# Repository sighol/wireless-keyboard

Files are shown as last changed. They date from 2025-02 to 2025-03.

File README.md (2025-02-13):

# Sighol-44

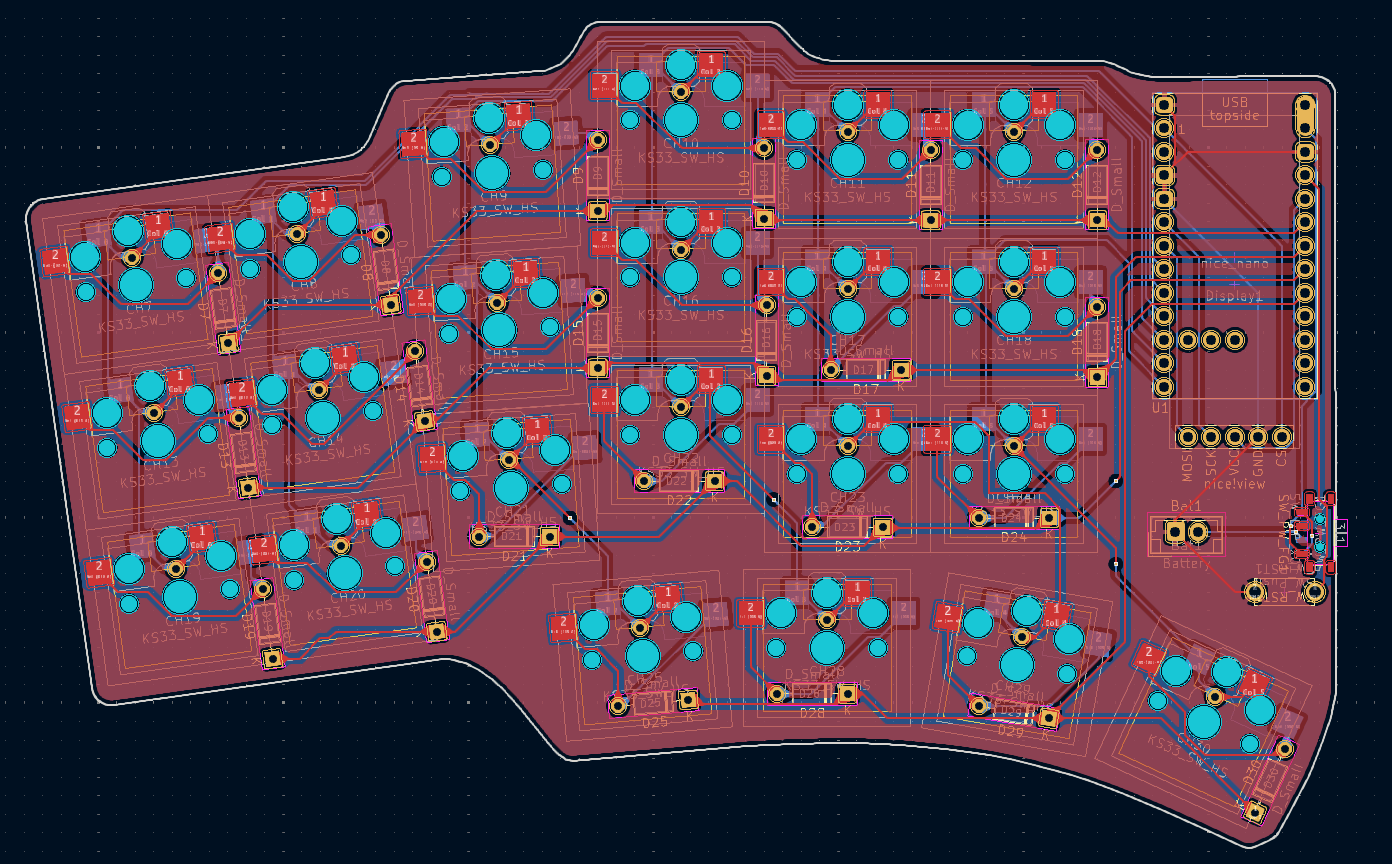
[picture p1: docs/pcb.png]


# Installation

Remember to add the [marbastlib](https://github.com/ebastler/marbastlib) symbol and footprints library.
Check the github page for installation instructions.

# Documentation

[Nice nano pinout and schematic](https://nicekeyboards.com/docs/nice-nano/pinout-schematic)

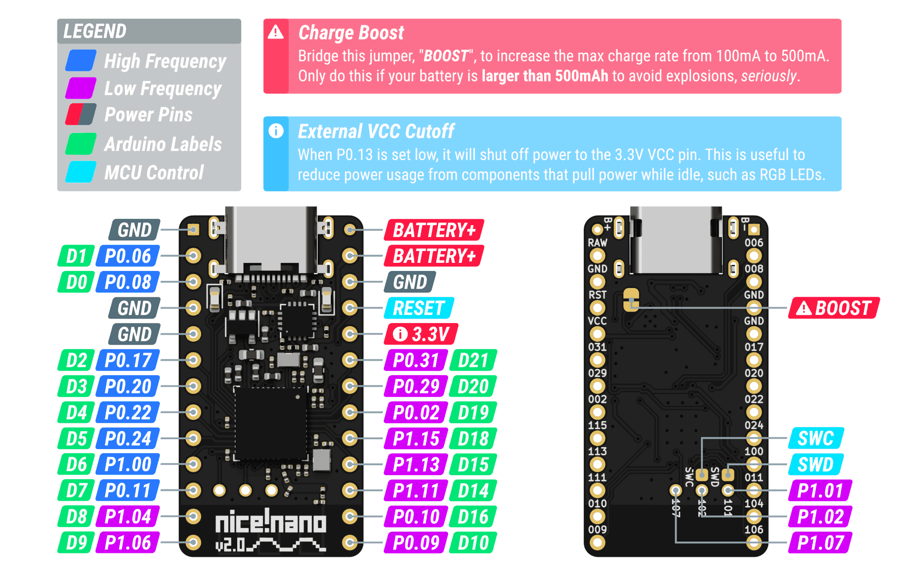
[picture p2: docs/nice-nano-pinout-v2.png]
Nice nano pinout


## [Video about batteries](https://www.youtube.com/watch?v=zoCKINGh2DQ)

- GEt mill max sockets that are avtagbare.
- Get taller ones so that battery fit underneath.
- Solder on the power switch early on. He said "the first thing", but I am not sure if
  that matters a lot.

## Nice View

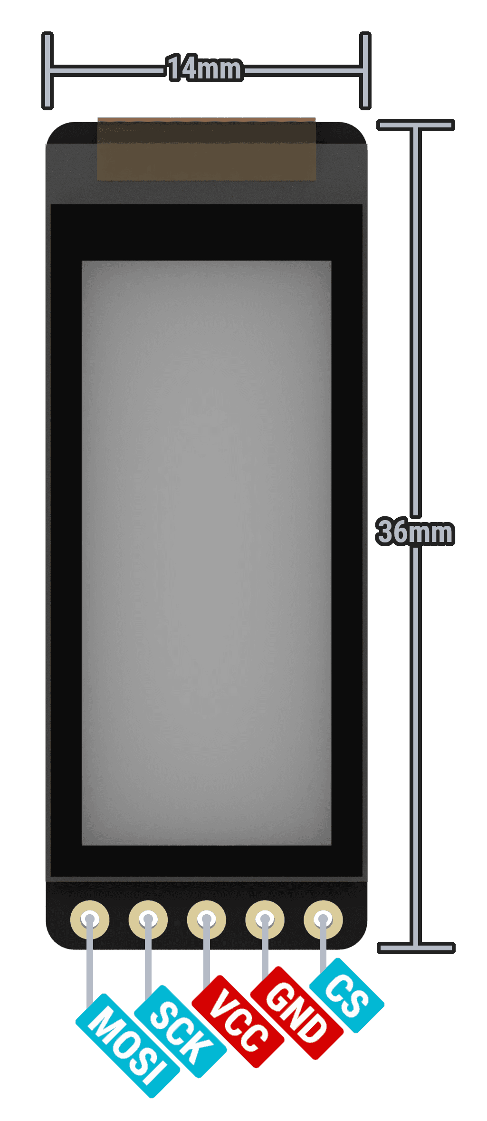
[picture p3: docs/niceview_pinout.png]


https://nicekeyboards.com/docs/nice-view/pinout-schematic#default-pins

- CS: D1/P0.06
- SCL: D2/P0.17
- MOSI: D3/P0.20

# Parts

- 2 x [Nice!Nano V2](https://42keebs.eu/shop/parts/controllers/nice-nano-v2-wireless-controller/)
- 2 x [Controller sockets/pins/headers medium](https://42keebs.eu/shop/parts/components/controller-sockets-pins-mill-max-generic/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). Medium will fit 3mm batteries.
- 1 x [Nice!view](https://42keebs.eu/shop/parts/niceview-power-efficient-lcd-display/). I only need one for the left half.
- 2 x [SDM power switch](https://42keebs.eu/shop/parts/components/power-switch/?attribute_type=Micro+SMD+SPDT).
- 2 x [reset switch](https://42keebs.eu/shop/parts/components/reset-switch/).
- [Batteries](https://www.aliexpress.com/item/1005007625961666.html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)

Total: 93.95 EUR on 42keebs.eu.

# TODO:

- Look for batteries and find one that fits.
- Check that the footprint for the RESET switch matches keeb42

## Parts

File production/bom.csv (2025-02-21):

Designator | Footprint | Quantity | Value | LCSC Part #
BAT1 | JST_EH_B2B-EH-A_1x02_P2.50mm_Vertical | 1 | Battery
CH10, CH11, CH12, CH13, CH14, CH15, CH16, CH17, CH18, CH19, CH20, CH21, CH22, CH23, CH24, CH25, CH28, CH29, CH30, CH7, CH8, CH9 | Kailh_socket_PG1350 reversible HS-only | 22 | KS33_SW_HS
D10, D11, D12, D13, D14, D15, D16, D17, D18, D19, D20, D21, D22, D23, D24, D25, D28, D29, D30, D7, D8, D9 | D_DO-35_SOD27_P7.62mm_Horizontal | 22 | D_Small
DISPLAY1 | nice_view | 1 | nice!view
SW_PW_FG1 | SW_MSK12C02-HB_reversible | 1 | SW_DIP_x01
SW_RST1 | SWITRONIC_0343HIM-180G | 1 | SW_Push

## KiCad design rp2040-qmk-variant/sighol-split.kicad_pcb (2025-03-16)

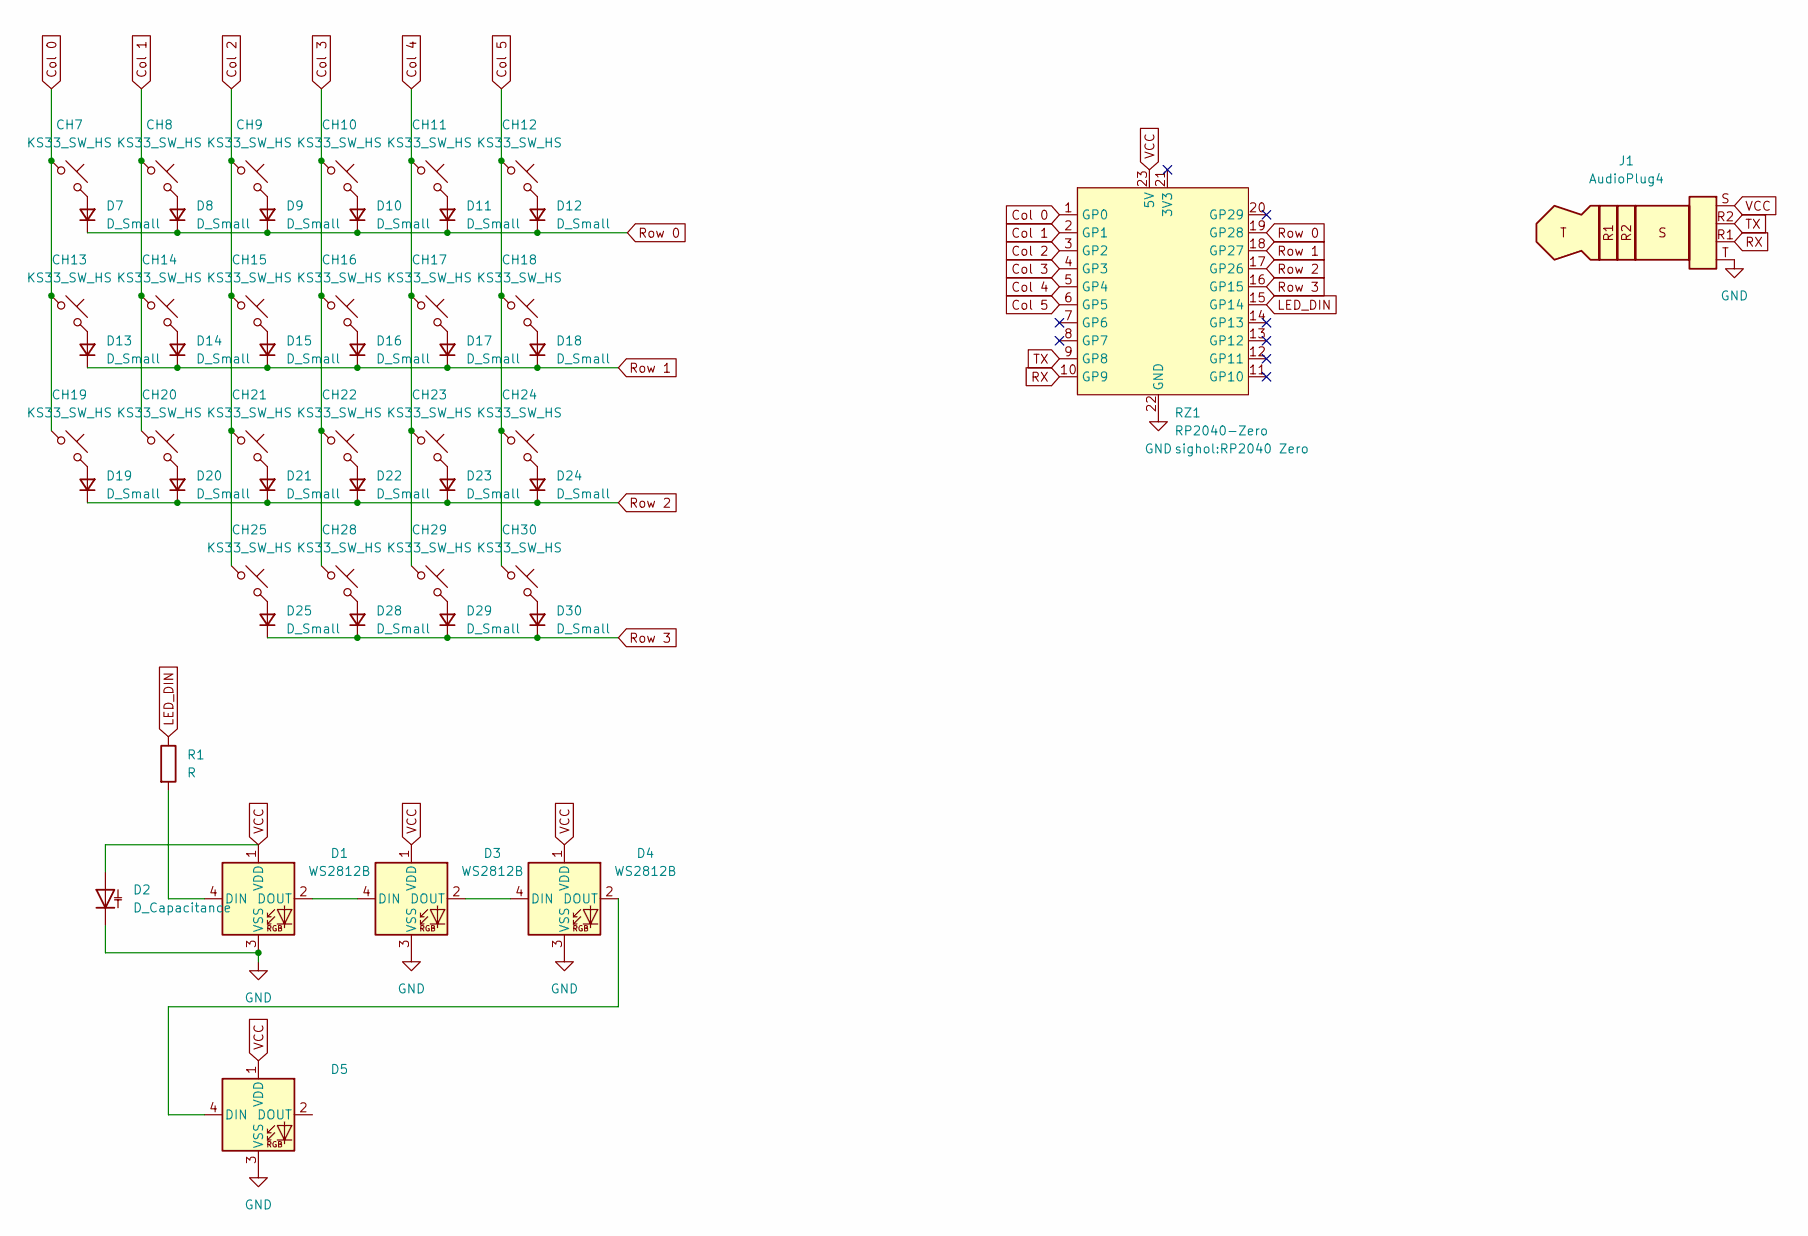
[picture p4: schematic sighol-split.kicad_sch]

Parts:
CH7, CH8, CH9, CH10, CH11, CH12, CH13, CH14, CH15, CH16, CH17, CH18, CH19, CH20, CH21, CH22, CH23, CH24, CH25, CH28, CH29, CH30: KS33_SW_HS; Kailh_socket_PG1350 reversible HS-only
D1, D3, D4, D5: WS2812B; LED_WS2812B_PLCC4_5.0x5.0mm_P3.2mm_reversible
D2: D_Capacitance; CP_Radial_D5.0mm_P2.00mm
D7, D8, D9, D10, D11, D12, D13, D14, D15, D16, D17, D18, D19, D20, D21, D22, D23, D24, D25, D28, D29, D30: D_Small; SOD-123 reversible
J1: AudioPlug4; TRRS-PJ-320A
R1: R; R_Axial_DIN0207_L6.3mm_D2.5mm_P2.54mm_Vertical
RZ1: RP2040-Zero; RP2040 Zero

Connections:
Col 0: CH7.1, CH13.1, CH19.1, RZ1.1 (GP0)
Col 1: CH8.1, CH14.1, CH20.1, RZ1.2 (GP1)
Col 2: CH9.1, CH15.1, CH21.1, CH25.1, RZ1.3 (GP2)
Col 3: CH10.1, CH16.1, CH22.1, CH28.1, RZ1.4 (GP3)
Col 4: CH11.1, CH17.1, CH23.1, CH29.1, RZ1.5 (GP4)
Col 5: CH12.1, CH18.1, CH24.1, CH30.1, RZ1.6 (GP5)
GND: D1.3 (VSS), D2.1 (K), D3.3 (VSS), D4.3 (VSS), D5.3 (VSS), J1.T, RZ1.22 (GND)
LED_DIN: R1.1, RZ1.15 (GP14)
unnamed: D1.4 (DIN), R1.2
unnamed: D1.2 (DOUT), D3.4 (DIN)
unnamed: D3.2 (DOUT), D4.4 (DIN)
unnamed: D4.2 (DOUT), D5.4 (DIN)
unnamed: CH7.2, D7.2 (A)
unnamed: CH8.2, D8.2 (A)
unnamed: CH9.2, D9.2 (A)
unnamed: CH10.2, D10.2 (A)
unnamed: CH11.2, D11.2 (A)
unnamed: CH12.2, D12.2 (A)
unnamed: CH13.2, D13.2 (A)
unnamed: CH14.2, D14.2 (A)
unnamed: CH15.2, D15.2 (A)
unnamed: CH16.2, D16.2 (A)
unnamed: CH17.2, D17.2 (A)
unnamed: CH18.2, D18.2 (A)
unnamed: CH19.2, D19.2 (A)
unnamed: CH20.2, D20.2 (A)
unnamed: CH21.2, D21.2 (A)
unnamed: CH22.2, D22.2 (A)
unnamed: CH23.2, D23.2 (A)
unnamed: CH24.2, D24.2 (A)
unnamed: CH25.2, D25.2 (A)
unnamed: CH28.2, D28.2 (A)
unnamed: CH29.2, D29.2 (A)
unnamed: CH30.2, D30.2 (A)
RX: J1.R1, RZ1.10 (GP9)
Row 0: D7.1 (K), D8.1 (K), D9.1 (K), D10.1 (K), D11.1 (K), D12.1 (K), RZ1.19 (GP28)
Row 1: D13.1 (K), D14.1 (K), D15.1 (K), D16.1 (K), D17.1 (K), D18.1 (K), RZ1.18 (GP27)
Row 2: D19.1 (K), D20.1 (K), D21.1 (K), D22.1 (K), D23.1 (K), D24.1 (K), RZ1.17 (GP26)
Row 3: D25.1 (K), D28.1 (K), D29.1 (K), D30.1 (K), RZ1.16 (GP15)
TX: J1.R2, RZ1.9 (GP8)
VCC: D1.1 (VDD), D2.2 (A), D3.1 (VDD), D4.1 (VDD), D5.1 (VDD), J1.S, RZ1.23 (5V)

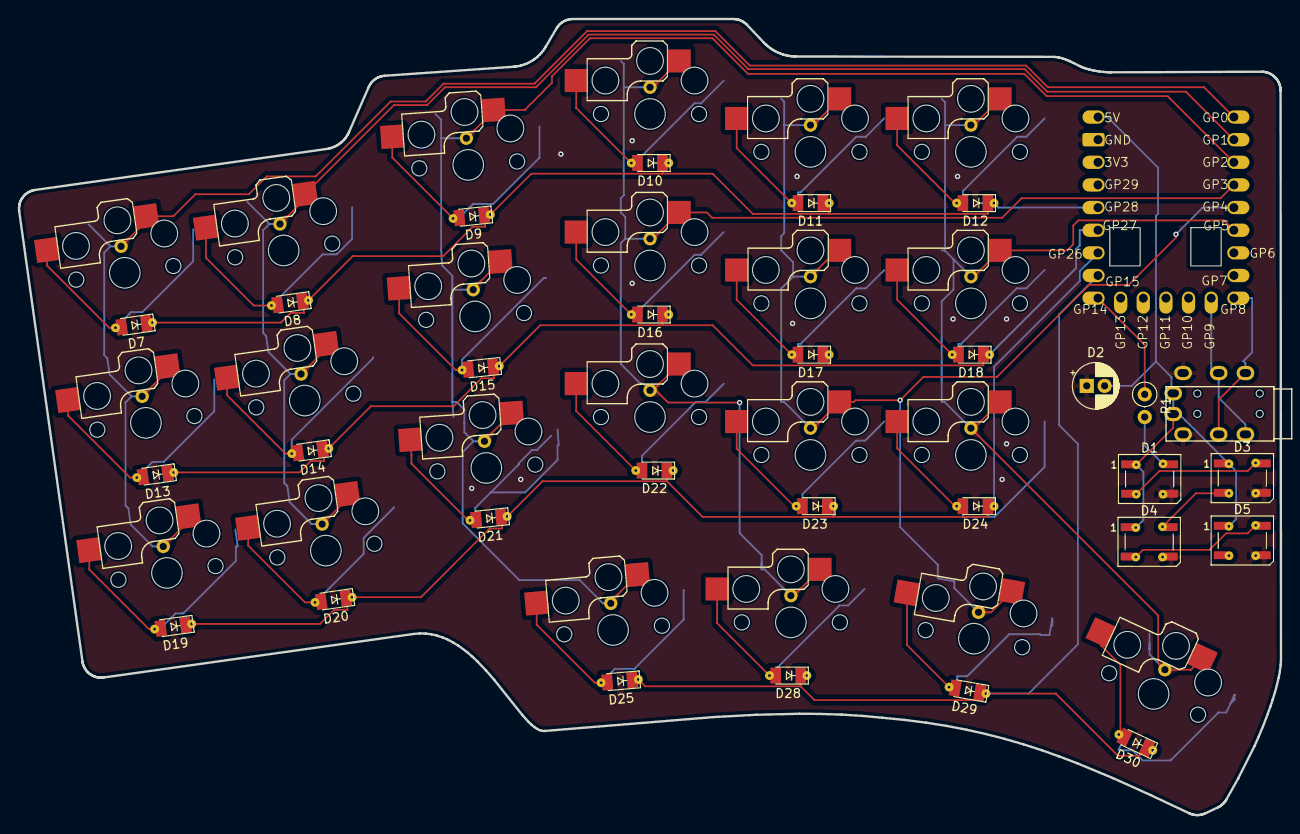
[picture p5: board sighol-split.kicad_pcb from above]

Board: 2 copper layers, 141.6 x 89.3 mm, 52 parts (1 on the bottom side), 41 nets.

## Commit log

2024-03-19 Created almost all routes: non-reversible left side
    [sighol-split2.kicad_pcb]
2024-03-19 connected all routes
    [sighol-split2.kicad_pcb]
2024-03-19 New edge cut
    [sighol-split2.kicad_pcb]
2024-03-21 new footprint
    [sighol-split2.kicad_pcb]
2024-03-21 more work
    [sighol-split2.kicad_pcb, sighol-split2.kicad_sch]
2024-03-21 More routing
    [sighol-split2.kicad_pcb, sighol-split2.kicad_sch]
2024-03-21 Full wiring
    [sighol-split2.kicad_pcb, sighol-split2.kicad_sch]
2024-03-22 moved right index row and fix teardrops
    [sighol-split2.kicad_pcb, sighol-split2.kicad_sch]
2024-03-22 More stuff
    [sighol-split2.kicad_pcb]
2024-03-22 edge cut
    [sighol-split2.kicad_pcb]
2024-03-22 Prettier edge cut
    [sighol-split2.kicad_pcb]
2024-09-21 Starting on new wireless build
    [sighol-split.kicad_pcb, sighol-split.kicad_sch]
2024-09-21 Move to sighol.kicad_sym
2024-09-21 edge-cut and blueprint
2025-02-10 remove nice-view-kicad submodule and remove display 2
    [sighol-split.kicad_sch]
2025-02-11 docs and more tracing and nice view
    [sighol-split.kicad_pcb, sighol-split.kicad_sch]
2025-02-12 Create reversible SW_MSK12CO2-HB, and connect all traces
    [sighol-split.kicad_pcb, sighol-split.kicad_sch]
2025-02-13 Move RST and PW, but leave disconnected
    [sighol-split.kicad_pcb]
2025-02-13 Smoother edge cut + moved mcu further down for more margin
    [sighol-split.kicad_pcb]
2025-02-13 Connect all traces again
    [sighol-split.kicad_pcb]
2025-02-13 Slightly smoother edge cut
    [sighol-split.kicad_pcb]
2025-02-13 copper layer fill zone
    [sighol-split.kicad_pcb]
2025-02-15 nothin much
    [sighol-split.kicad_pcb]
2025-02-16 Ground fill and connect nicenano to 3V3 instead of Bat+
    [sighol-split.kicad_pcb, sighol-split.kicad_sch]
2025-02-21 Fix RESET switch
    [sighol-split.kicad_pcb, sighol-split.kicad_sch]
2025-02-21 fabrication n all
    [bom.csv, designators.csv, positions.csv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]
2025-03-11 Fix RP2040 build
    [bom.csv, designators.csv, positions.csv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]
2025-03-11 rp2040: no-connect
    [sighol-split.kicad_pcb, sighol-split.kicad_sch]
2025-03-11 Make footprint for diode nicer
    [sighol-split.kicad_pcb]
2025-03-11 More footprint silkscreens
    [sighol-split.kicad_pcb]
2025-03-16 SMD diodes + holes for the boot and reset pins
    [sighol-split.kicad_pcb, sighol-split.kicad_sch]
2025-03-16 Added LEDs that I think are meant to be used for indoor lightning
    [sighol-split.kicad_pcb, sighol-split.kicad_sch]
2025-03-16 fixup! SMD diodes + holes for the boot and reset pins
2025-03-16 To production, again
    [bom.csv, designators.csv, positions.csv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]
2025-04-15 Add rp2040-qmk-variant
    [bom.csv, designators.csv, positions.csv]
